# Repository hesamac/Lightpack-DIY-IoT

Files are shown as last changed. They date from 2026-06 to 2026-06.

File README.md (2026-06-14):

# Lightpack DIY — ESP32-C6 · Matter/HomeKit · Ambilight

> Replace the dead original Lightpack microcontroller (AT90USB162) with an
> **ESP32-C6**, driving the existing **DM631** LED drivers, and expose the device
> to **Apple Home (Matter)** *and* **screen-sync Ambilight** — on one chip, no
> extra hardware, no PC required for normal use.

**Status: working end-to-end.** ✅ 10 RGB zones controllable from Apple Home/Siri,
**and** live screen Ambilight via HyperHDR.

---

## What it does

The [Lightpack](https://github.com/Atarity/Lightpack) is an open-source ambient
backlight, originally a USB device driven by the (now-dead-on-macOS) Prismatik
app. This project rips out the USB MCU and turns the board into:

- A **Matter / Apple Home** smart light — **10 independent RGB zones**, each its
  own tile with tap-to-toggle, color, and brightness; controllable by Siri.
- A **wireless Ambilight** — a desktop tool (**HyperHDR**) streams screen-edge
  colors over Wi-Fi and the LEDs follow the screen in real time.

Both run in the same firmware and switch automatically: Ambilight takes over
while it's streaming, and the device returns to its Apple Home state ~2 s after
streaming stops.

---

## Hardware

| Part | Notes |
|---|---|
| Lightpack board (rev 6.x) | Original PCB with two SiTI **DM631** LED drivers (10 zones) |
| ESP32-C6-DevKitM-1 | RISC-V, Wi-Fi 6 + BLE, 4 MB flash, 3.3 V I/O |
| 12 V supply | Powers the LED rail via the barrel jack |
| 5 V source (USB charger or MP1584 buck) | Powers the board **logic** + the ESP32 |

> 🧩 **Stealth retrofit:** all the added electronics (ESP32-C6 + buck converter)
> fit **inside the original Lightpack enclosure**, so the finished unit keeps the
> original product's look — it looks just like a stock Lightpack from the outside.

### Wiring — ESP32-C6 → Lightpack (3 signals + ground)

| Signal | ESP32-C6 | Lightpack tap point |
|---|---|---|
| CLK | GPIO6  | IC1 pin 15 / DM631 DCK |
| DATA | GPIO7  | IC1 pin 16 / DM631 DAI |
| LATCH  | GPIO14 | IC1 pin 14 / DM631 /LAT |
| GND | GND | common ground (mandatory) |

> Only these three signals + GND go to the board. **Do not** connect the ESP32's
> 3.3 V/5 V pins to the Lightpack.

### Power — the key gotcha

The DM631 **logic** (VDD, ~5 V) is fed only from the board's **USB connector**,
*not* from the barrel jack (the jack/diode D2 feeds the LED rail only). So:

```
12 V barrel jack ──► LED anode rail (isolated by D2)
5 V (charger / MP1584) ──► board USB port ──► DM631 logic VDD (REQUIRED)
                       └──► ESP32-C6 power
GND ───────────────────── shared by all three
```

If the board's USB 5 V is missing, the DM631s have no logic power and the LEDs
output garbage. (3.3 V from the ESP works in practice despite the DM631's 5 V
logic-high spec; if you ever see flicker, a 74AHCT125 buffer or a 4.5 V logic
rail fixes the margin.)

### Retiring the AT90USB162 (IC1)

IC1 is disabled by **grounding its RESET pin** (all its I/O go high-impedance, so
it can't fight the ESP on the shared bus). Optionally cut IC1 pins 14/15/16 to
remove it from the bus entirely.

---

## DM631 driver

- 3-wire bit-bang (CLK/DATA/LATCH), no chip-select, MSB-first.
- 12 bits per channel (0–4095). Two DM631s daisy-chained, 32×12 bits per frame.
- **Channel order per zone: B → G → R** (matches the original woodenshark firmware).
- A small **`led_to_zone[]`** table maps logical zones to the socket numbers
  printed on the enclosure (the near chip is wired in a scrambled order).

> If only ~5 zones respond, the CLK/LATCH link between the two DM631s may need a
> jumper.

---

## Matter / Apple Home

- **Topology:** a Matter **bridge** — one Aggregator + **10 bridged Extended
  Color Lights** ("LED 1"…"LED 10"), so each zone is a first-class HomeKit
  accessory (own tile, tap-to-toggle, room, scenes).
- **Color:** HueSaturation-native (Apple drives color via `MoveToHueAndSaturation`).
  Advertises **HS + XY only** (`0x09`) — **Color Temperature is deliberately
  dropped** to dodge a HomeKit bug that paints the swatch a default light-blue
  for lights exposing CT+HS together.
- **Commissioning:** BLE. **Pairing code: `20202021`.**
- Gamma 2.2, per-zone NVS persistence, device identity (manufacturer/model/serial).

---

## Ambilight (screen sync)

- A Wi-Fi UDP receiver listens on **two** protocols:
  - **DDP** (port **4048**) — recommended; what **HyperHDR**'s "DDP" device uses.
  - **WLED** realtime (port **21324**, DRGB/DNRGB) — for WLED-native tools + testing.
- Auto Home↔Ambilight switching with a 2 s idle revert that restores the Apple
  Home colors.

### HyperHDR setup (macOS)

1. Install **HyperHDR** (`…-macOS-arm64.dmg` for Apple Silicon) from its
   [GitHub releases](https://github.com/awawa-dev/HyperHDR/releases). First launch:
   right-click → Open; grant **Screen Recording** permission.
2. **LED Layout** → *Classic*, edge counts summing to **10**.
3. **LED Controller** → type **DDP**, host = ESP32 IP, port **4048**, order **RGB**.
4. Enable the macOS screen grabber. If dim, raise HyperHDR brightness/gamma.

Quick firmware-only test (no HyperHDR) — WLED broadcast "all red":
```bash
python3 -c "
import socket, time
s = socket.socket(socket.AF_INET, socket.SOCK_DGRAM)
s.setsockopt(socket.SOL_SOCKET, socket.SO_BROADCAST, 1)
pkt = bytes([2,2]) + bytes([255,0,0])*10
for _ in range(50):
    s.sendto(pkt, ('255.255.255.255', 21324)); time.sleep(0.1)
"
```

---

## Build & flash

```bash
# Each new terminal:
source ~/esp/esp-idf/export.sh
source ~/esp/esp-matter/export.sh    # needed for builds (sets ESP_MATTER_PATH)

cd firmware
idf.py set-target esp32c6            # first time only
idf.py -p /dev/cu.usbserial-XXX build flash monitor
```

- Run `idf.py` from `firmware/` (the repo-root `CMakeLists.txt` is a junk
  placeholder). The serial port name varies with the USB socket — check
  `ls /dev/cu.*`. If "port busy": `lsof -t /dev/cu.usbserial-XXX | xargs kill`.

### Firmware layout (`firmware/main/`)

```
dm631.{c,h}              DM631 bit-bang driver + zone→socket remap
app_priv.h               shared types / defaults
app_driver.cpp           Matter color math → output layer
app_main.cpp             Matter node, bridge endpoints, Wi-Fi, startup
output_controller.{cpp,h}  single LED output layer: Home/Ambilight mode + mutex
ambilight_udp.{cpp,h}    Wi-Fi UDP receiver (WLED 21324 + DDP 4048)
```

### Languages & toolchain

- **C++** — all Matter/application code (`app_main`, `app_driver`,
  `output_controller`, `ambilight_udp`); the esp-matter / CHIP (connectedhomeip)
  SDK is C++, so the app is too.
- **C** — the `dm631` LED driver (GPIO bit-bang), called from C++ via `extern "C"`.
- Built with **ESP-IDF** + **esp-matter**, **RISC-V GCC** toolchain, target
  **ESP32-C6**. (The Ambilight test snippet is Python and runs on the Mac, not
  the device.)

---

## Status

| Item | Status |
|---|---|
| Hardware bring-up (10 zones, correct colors) | ✅ |
| Apple Home: 10 zones, color/brightness, per-tile toggle | ✅ |
| Color slider correct (light-blue bug fixed) | ✅ |
| Multi-light / Siri responsiveness | ✅ |
| Device identity (manufacturer/model/serial) | ✅ |
| Ambilight (WLED + DDP), HyperHDR verified | ✅ |
| Chip-temperature sensor | ❌ removed — Apple Home won't render bridged Matter sensors |

See [`docs/`](docs/) for the detailed dev logs.

---

## Safety

This is a do-it-yourself project that modifies the electronics of a powered
device. **Build and use it at your own risk.**

- **Power rails:** the LED rail runs at **12 V** (barrel jack); the board logic +
  ESP32 run at **5 V** (board USB). Don't cross-wire the rails, and never feed
  12 V into the ESP32 or its GPIOs.
- **Common ground:** all supplies (12 V, 5 V, ESP32) must share a ground.
- **LED current** flows through the DM631 drivers and the 12 V rail — *not*
  through the ESP32. Size the 12 V supply for your LEDs.
- **Heat:** the electronics sit inside the original enclosure; ensure adequate
  cooling. There is **no firmware thermal protection** (that feature was removed).
- This is a hobby project, **not a certified or commercial product**.

---

## Disclaimer

This is an independent, non-commercial DIY project. It is **not affiliated with,
endorsed by, or certified by** the original Lightpack project / woodenshark,
Apple, the Connectivity Standards Alliance (Matter), Espressif, WLED, or HyperHDR.
All trademarks belong to their respective owners.

The firmware uses Matter **test** vendor/product IDs and is **not** a certified
Matter or "Works with Apple Home" product — references to "Apple Home" and
"Matter" describe local compatibility only. The software is provided "as is",
without warranty of any kind (see [`LICENSE`](LICENSE)).

---

## Credits & upstream

This project builds on the original **Lightpack** by woodenshark / Atarity — the
ambient-light hardware, the original AVR firmware, and its documentation. Those
upstream sources are **GPL/CC licensed and are not bundled in this repository**;
get them from the original project:

- Original Lightpack: <https://github.com/Atarity/Lightpack>
- Original firmware: <https://github.com/woodenshark/Lightpack>

This repo contains **only the new ESP32-C6 firmware**. The DM631 driver is a
clean re-implementation; the original `LedDriver.c` is credited in the source
comments.

---

## License

This project's own code (the ESP32-C6 firmware in `firmware/`) is released under
the **MIT License** — see [`LICENSE`](LICENSE). Third-party components (ESP-IDF,
esp-matter, etc.) retain their own licenses, and the original Lightpack sources
are not included here (see **Credits & upstream** above).

---

## References

- [Lightpack original firmware](https://github.com/woodenshark/Lightpack)
- [esp-matter SDK](https://github.com/espressif/esp-matter)
- [HyperHDR](https://github.com/awawa-dev/HyperHDR)
- [ESP32-C6-DevKitM-1](https://docs.espressif.com/projects/esp-dev-kits/en/latest/esp32c6/esp32-c6-devkitm-1/)
- [SiTI DM631 datasheet](https://www.siti.com.tw/product/spec/LED/DM631.pdf)

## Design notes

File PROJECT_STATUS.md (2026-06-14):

# Lightpack DIY — ESP32-C6 · Matter/HomeKit · Ambilight — Project Status

**Last updated:** 2026-06-14  
**Status:** ✅ **Complete and working** — Apple Home (10 zones) + screen Ambilight.
**Goal:** Replace the dead Lightpack MCU (AT90USB162) with an ESP32-C6 driving the
existing DM631 LED drivers, exposed to Apple Home via Matter, plus a Wi-Fi UDP
Ambilight receiver for screen sync.

> ⚠️ The **section below this divider reflects the current, verified state.** The
> numbered sections further down are historical reference from the 2026-05-25
> bring-up; a few claims there were later superseded (corrected here and inline).
> Full history: `docs/DEVLOG-*.md`.

## Current status (2026-06-14)

### Working
- **10 RGB zones** via two daisy-chained DM631 drivers; channel order
  **B → G → R** (confirmed); logical zones remapped to the printed socket numbers
  via `led_to_zone[]`.
- **Apple Home bridge:** Aggregator + 10 bridged Extended Color Lights
  ("LED 1"…"LED 10") — each a tile with tap-to-toggle, color, brightness; Siri works.
- **Color:** HueSaturation-native; advertises **HS + XY only (`0x09`)** — Color
  Temperature deliberately dropped to fix the HomeKit "light-blue swatch" bug.
  Gamma 2.2, per-zone NVS persistence, device identity set. Pairing code **20202021**.
- **Ambilight:** Wi-Fi UDP receiver — **DDP** (port **4048**, for HyperHDR) +
  **WLED** realtime (port **21324**, DRGB/DNRGB). Auto Home↔Ambilight switching,
  2 s idle revert that restores the Apple Home state. Verified with HyperHDR (macOS).
- **Enclosure:** all added electronics (ESP32-C6 + buck converter) fit inside the
  **original Lightpack housing** — the finished build keeps the original product's
  appearance (stealth retrofit).

### Hardware — corrections vs. the historical sections below
- **Wiring:** GPIO6 = CLK, GPIO7 = DATA, GPIO14 = LATCH, GND. Three signals + ground.
- **Power:** 12 V on the barrel jack → LED rail (isolated by D2). The DM631
  **logic VDD (~5 V) comes from the board's USB connector and is REQUIRED** — not
  from the jack. *(The old "leave USB unplugged to isolate the AVR" note is wrong:
  the logic needs that USB 5 V; without it the LEDs output garbage.)* ESP32 also
  powered from 5 V. ~3.3 V signalling works in practice.
- **AT90USB162 (IC1)** isolated by **grounding its RESET pin** (I/O → Hi-Z).

### Languages & toolchain
- **C++** — all Matter/application code (`app_main.cpp`, `app_driver.cpp`,
  `output_controller.cpp`, `ambilight_udp.cpp`); required by the esp-matter /
  CHIP (connectedhomeip) C++ SDK.
- **C** — the `dm631` LED driver (GPIO bit-bang), called from C++ via `extern "C"`.
- Built with **ESP-IDF** + **esp-matter** using the **RISC-V GCC** toolchain,
  target **ESP32-C6**. (The Ambilight test snippet is Python, run on the Mac.)

### Removed
- **Chip-temperature sensor.** Firmware was proven correct (value read, scaled,
  reported), but Apple Home does **not** render *bridged* Matter sensor values
  (known Apple-side limitation — open esp-matter issues). Reverted.

### Resolved since 2026-05-25 (listed as "open" in the historical sections below)
All 10 zones working · color wheel/slider correct · multi-zone + Siri
responsiveness · fabric/commissioning · per-tile tap-to-toggle.

---

## 1. Hardware

### ESP32-C6-DevKitM-1

| Property | Value |
|---|---|
| Module | ESP32-C6-MINI-1 |
| Chip | ESP32-C6FH4 |
| Flash | 4 MB (in-package) |
| I/O voltage | 3.3 V |
| USB ports | USB-C (native USB 2.0 FS) + USB-C to UART bridge |
| Boot button | GPIO9 (strapping pin, active LOW) |
| On-board RGB LED | GPIO8 (do not use for SPI) |

### Lightpack board (standard revision 6.x)

| Component | Part | Notes |
|---|---|---|
| LED driver IC2 | SiTI DM631 | Controls zones 5–9 |
| LED driver IC3 | SiTI DM631 | Controls zones 0–4 |
| Current-limit resistors | R5, R6 = 3.9 kΩ | Use 3 kΩ only if swapped to DM633 |
| LED ports | 10 total | Each port = 1 RGB colour zone (3-LED strip) |
| Original MCU | Atmel AT90USB162 | Replaced by ESP32-C6 |
| Original interface | USB HID | Replaced by WiFi + Matter |

---

## 2. Pin Assignments

### ESP32-C6 → Lightpack DM631 wiring

| Signal | ESP32-C6 GPIO | Lightpack pad | Notes |
|---|---|---|---|
| CLK (DCK) | **GPIO6** | AT90USB162 SCK pin | SPI2 / FSPICLK |
| DATA (DAI) | **GPIO7** | AT90USB162 MOSI pin | SPI2 / FSPID |
| LATCH (LAT) | **GPIO14** | AT90USB162 LATCH pin | Software GPIO — NOT SPI CS |
| GND | GND | GND | Common ground required |
| 3.3 V | 3V3 | VCC (logic) | ESP32-C6 supplies 3.3 V logic only |

> **Power note:** The Lightpack's LEDs run at 5 V from an external supply.
> The DM631 logic interface runs at 3.3 V and is directly compatible with
> the ESP32-C6. Do NOT connect the 5 V LED rail to the ESP32-C6.

### ESP32-C6 J1 header reference (relevant pins)

| J1 Pin | GPIO | Function used |
|---|---|---|
| 11 | GPIO6 | CLK → DM631 DCK |
| 12 | GPIO7 | MOSI → DM631 DAI |
| 13 | GPIO14 | LATCH → DM631 LAT |
| 1 | 3V3 | Logic power (optional if Lightpack board has own 3.3 V reg) |
| GND | GND | Common ground |

---

## 3. DM631 Protocol — Verified Details

Source: woodenshark/Lightpack firmware (`Firmware/LedDriver.c`), confirmed against
SiTI DM631/DM633 datasheet and Ontaelio/DMdriver Arduino library.

### Electrical

- **Interface:** 3-wire (CLK, DATA, LATCH) — no chip-select
- **Logic levels:** 3.3 V compatible
- **Clock:** 1 MHz used in firmware (DM631 supports higher; 1 MHz is conservative for ribbon cable)

### SPI parameters

| Parameter | Value |
|---|---|
| SPI mode | Mode 0 (CPOL=0, CPHA=0) |
| Bit order | **MSB first** |
| Bits per channel | **12 bits** (0 = off, 4095 = full brightness) |
| Channel order per LED | **B → G → R** (blue clocked in first) |
| Channels per IC | 16 (15 used for 5 RGB LEDs + 1 padding) |
| ICs in chain | 2 (daisy-chained: ESP32 → IC1 → IC2) |

### Frame structure (48 bytes = 384 bits)

```
Byte offset   Content
──────────────────────────────────────────────────────────────────
 0– 2         0x000 (12-bit padding for IC2)
 3– 5         zone 5 Blue (12 bit), zone 5 Green (12 bit)  [packed]
 6– 8         zone 5 Red (12 bit),  zone 6 Blue (12 bit)   [packed]
 ...          zones 6, 7, 8, 9 follow in the same B-G-R order
 24–26        0x000 (12-bit padding for IC1)
 27–29        zone 0 Blue, zone 0 Green
 ...          zones 1, 2, 3, 4 follow
 45–47        zone 4 Green, zone 4 Red
```

Every two 12-bit values are packed into three bytes (MSB-first):
```
byte[0] = v0[11:4]
byte[1] = v0[3:0] | v1[11:8]
byte[2] = v1[7:0]
```

### LATCH pulse

- Fires **once**, **after** all 384 bits are clocked in for both ICs
- GPIO14: LOW → **HIGH** → LOW (active-high single pulse)
- Transfers shift-register contents to output latches on both ICs simultaneously
- No minimum pulse-width delay required at 3.3 V / ESP32 GPIO speeds (~20 ns)

### DM631 vs DM633 difference

DM631 and DM633 have **identical** shift-in protocol. DM633 adds a 7-bit global
brightness register not present on DM631. The firmware works for both chips.

---

## 4. Software / Toolchain

### Development environment

| Tool | Version | Location |
|---|---|---|
| ESP-IDF | v5.3.0 | `~/esp/esp-idf` |
| RISC-V GCC | 13.2.0 | `~/.espressif/tools/riscv32-esp-elf/` |
| OpenOCD | v0.12.0-esp32 | `~/.espressif/tools/openocd-esp32/` |
| esp-matter | latest main | `~/esp/esp-matter` |
| Python (venv) | 3.14.4 | `~/.espressif/python_env/idf5.3_py3.14_env/` |

**To activate in a new terminal:**
```bash
source ~/esp/esp-idf/export.sh
source ~/esp/esp-matter/export.sh
```

### Firmware project

**Location:** `~/Documents/Project/Lightpack\ DIY/firmware/`

```
firmware/
├── CMakeLists.txt                # top-level build, links to esp-matter
├── partitions.csv                # 4 MB flash layout with OTA + factory NVS
├── sdkconfig.defaults            # BT, WiFi, Matter cluster pruning
├── sdkconfig.defaults.esp32c6    # target lock
└── main/
    ├── CMakeLists.txt
    ├── dm631.h / dm631.c         # DM631 SPI driver
    ├── app_priv.h                # shared types and defaults
    ├── app_driver.cpp            # Matter ↔ DM631 bridge (colour math, per-zone state)
    └── app_main.cpp              # Matter node, 10 endpoints, event loop
```

### Build status

| Item | Status |
|---|---|
| `idf.py set-target esp32c6` | ✓ |
| `idf.py build` | ✓ — zero errors, 1.71 MB (13% headroom) |
| Binary | `build/lightpack.bin` |
| Matter device type | Extended Color Light × 10 (one per zone) |
| Colour modes supported | On/Off, Brightness, Hue/Saturation, Color Temperature, CIE XY |
| Per-zone independent control | ✓ 10 separate Matter endpoints → 10 HomeKit tiles |
| RGB colour wheel in Apple Home | ✓ confirmed (FeatureMap + ColorCapabilities fix) |
| NVS persistence | ✓ (deferred write per-endpoint, per-zone) |
| OTA update support | ✓ (partition table includes OTA slots) |

### Known TODOs in firmware

- **Button (GPIO9):** `app_driver_button_init()` returns NULL — button
  toggle and 5-second factory-reset long-press not yet wired in.
  Workaround: `idf.py erase-flash flash` for factory reset.
- **Prismatik API (future):** TCP:3636 Prismatik API for
  computer-screen-reactive ambilight. HomeKit per-zone control is now
  fully implemented; Prismatik is a future enhancement.
- **BLE re-advertising after fabric removal:** `kBLEDeinitialized` may
  fire before `kFabricRemoved`, preventing BLE re-advertising. Needs
  investigation (not reproduced since switching to `kAllSupported`).
- **Hardware wiring:** Not yet connected to Lightpack board (see § 5).

---

## 5. Wiring Status

| Connection | Status |
|---|---|
| ESP32-C6 GPIO7 → Lightpack DATA pad (right edge / J1) | ⬜ Not yet wired |
| ESP32-C6 GPIO6 → Lightpack CLK pad (right edge / J1) | ⬜ Not yet wired |
| ESP32-C6 GPIO14 → Lightpack LATCH pad (right edge / J1) | ⬜ Not yet wired |
| ESP32-C6 GND → Lightpack GND pad (right edge / J1) | ⬜ Not yet wired |
| 5 V external supply → Lightpack LED rail | ⬜ Not yet connected |
| AT90USB162 removed / bypassed | ⬜ Pending |

### Preferred solder points — NEXT_BOARD connector (J1), right edge of PCB

The Lightpack board has five dedicated labeled pads on its right edge (the J1
"NEXT_BOARD" daisy-chain connector). These are the easiest and most reliable
connection points — no need to solder directly to IC2's SOP24 pins.

```
Lightpack right edge          ESP32-C6 DevKitM-1
────────────────────          ──────────────────
DATA  pad  ──────────────────► J1 Pin 12 (GPIO7)
CLK   pad  ──────────────────► J1 Pin 11 (GPIO6)
LATCH pad  ──────────────────► J1 Pin 13 (GPIO14)
GND   pad  ──────────────────► GND
VCC   pad  — leave unconnected (ESP32-C6 has its own 3.3 V supply)
```

> **Note:** The DATA pad on J1 connects to the same `DATA1` net as IC2 Pin 2.
> Soldering to either point is electrically identical; J1 is far easier.

---

## 6. Next Steps — Hardware Build

### Step 1 — Bypass or remove the AT90USB162

The original MCU drives the same CLK/DATA/LAT lines. It must be
electrically isolated before the ESP32-C6 is connected, or it will
fight for the bus.

Options (choose one):
- **Remove the IC** (recommended if you have hot-air rework tools)
- **Lift pins** DCK, DAI, LAT on the AT90USB162 so it cannot drive the lines
- **Leave it in reset** by holding the RESET pin LOW (check schematic for reset pull-up)

### Step 2 — Locate the DM631 signal pads on the Lightpack board

Using the Lightpack 6.0L schematic (Eagle CAD files in the Lightpack GitHub repo):
- Find the pads where the AT90USB162 drives IC2/IC3 (the two DM631 chips)
- CLK and DATA are shared between both ICs (daisy-chained)
- LAT is a single line that latches both ICs simultaneously

### Step 3 — Wire ESP32-C6 to Lightpack board

Use short, direct wires (< 15 cm preferred for signal integrity at 1 MHz).

Solder to the **J1 "NEXT_BOARD" pads on the right edge** of the Lightpack PCB
(five labeled pads: VCC, GND, DATA, CLK, LATCH):

```
ESP32-C6 DevKitM-1          Lightpack board (J1 right-edge pads)
──────────────────          ──────────────────────────────────────
J1 Pin 12 (GPIO7)  ──────►  DATA  pad
J1 Pin 11 (GPIO6)  ──────►  CLK   pad
J1 Pin 13 (GPIO14) ──────►  LATCH pad
GND                ──────►  GND   pad
                             VCC   pad — leave unconnected
```

No level shifter needed — both sides are 3.3 V logic.

> **Alternative:** DATA can also be soldered directly to IC2 Pin 2 (DAI) on
> the DM631 chip — same net, but the J1 edge pad is far easier to work with.

### Step 4 — Power

- The ESP32-C6-DevKitM-1 is powered independently via its own USB-C cable
- The Lightpack board's 5 V LED supply connects to its existing power jack
- The shared GND is the only electrical connection required for the power domains

### Step 5 — Flash and commission

```bash
# In a terminal with environment sourced:
cd ~/Documents/Project/Lightpack\ DIY/firmware

# Flash (NVS preserved — use if already commissioned)
idf.py -p /dev/cu.usbserial-210 flash

# Flash + erase (wipes commissioning data — use for first-time or re-commissioning)
idf.py -p /dev/cu.usbserial-210 erase-flash flash
```

First boot output will show a Matter QR code. Open the iPhone **Home** app
→ Add Accessory → scan the QR code. All 10 zones appear as separate tiles.

### Step 6 — Verify DM631 output

At boot, the firmware runs a 3-colour diagnostic sequence (RED → GREEN → BLUE,
1.5 s each) across all zones. Confirm all 10 LED strips cycle through the colours
in the correct order. If a strip shows the wrong colour, cross-reference the
zone index with the DM631 channel mapping in § 3.

### Step 7 — Name zones in the Home app

After confirming hardware, rename zones in the Home app (tap tile → ✎) to
match physical strip positions. Reference mapping:

| HomeKit tile | Endpoint | DM631 IC | Physical position (to be confirmed) |
|---|---|---|---|
| Lightpack (Zone 0–4) | 1–5 | IC3 (near, zones 0–4) | TBD after hardware test |
| Lightpack (Zone 5–9) | 6–10 | IC2 (far, zones 5–9) | TBD after hardware test |

### Step 8 — Add button support (optional)

Edit `main/app_driver.cpp` — the `app_driver_button_init()` stub is
already in place. Wire the ESP32-C6 BOOT button (GPIO9, active LOW) to
toggle on/off and trigger factory reset on 5-second press.

### Step 9 — Prismatik API (future)

Add a TCP server on port 3636 implementing the Prismatik API v1.3
(`lock`, `setcolor:N-R,G,B;`, `setbrightness`, `setstatus`) so the
existing Prismatik ambilight software can drive per-zone colours over WiFi.

---

## 7. References

| Document | Location |
|---|---|
| Lightpack DIY build guide | `Lightpack-docs-master/Lightpack_DIY.md` |
| Lightpack basics | `Lightpack-docs-master/Lightpack_basics.md` |
| Prismatik API v1.3 | `Lightpack-docs-master/Prismatik_API.md` |
| ESP32-C6-DevKitM-1 datasheet | `datenblatt-2992163-espressif-esp32-c6-devkitm-1-n4-entwicklungsboard.pdf` |
| Lightpack firmware source | https://github.com/woodenshark/Lightpack |
| DM631 Arduino library | https://github.com/Ontaelio/DMdriver |
| ESP-IDF docs | https://docs.espressif.com/projects/esp-idf/en/v5.3/ |
| esp-matter docs | https://docs.espressif.com/projects/esp-matter/en/latest/ |

---

## 8. Session Log — 2026-05-10

### What was done

The device had already been wired, flashed, and commissioned in earlier sessions
(see `lightpack-diy-session-log.md`). This session focused on two software bugs
that prevented correct behaviour in Apple Home.

---

### Bug 1 — Apple Home shows warm/cool slider instead of RGB colour wheel

**Symptom:** After commissioning, the accessory tile in Apple Home only offers a
colour-temperature (warm/cool) slider. No RGB colour wheel is reachable.

**Root cause — ODR violation in the esp-matter SDK:**
Both `esp_matter_cluster.cpp` (legacy) and the generated
`extended_color_light_device.cpp` export the symbol
`esp_matter::cluster::color_control::create()`. The two translation units define
different `config_t` structs with `color_capabilities` at different byte offsets.
When the legacy version wins the linker race it reads from the wrong offset and
writes `0` to the `ColorCapabilities` attribute. Apple Home interprets
`ColorCapabilities = 0` as "no colour modes supported" and hides the colour wheel.

**Fix applied (`main/app_main.cpp`):**
After the endpoint is created, write `ColorCapabilities = 0x0009`
(bit 0 = HueSaturation, bit 3 = XY) directly onto the live attribute object —
this bypasses the struct-offset mismatch entirely.

**Status: ❌ Partially fixed.** ColorCapabilities was set correctly but Apple Home
still showed the temperature slider. Full fix completed in Session 2026-05-25.

---

### Bug 2 — Device undiscoverable after removing accessory from Apple Home

**Symptom:** After removing the accessory in Apple Home, the device never reappears
under "Nearby Accessories" and cannot be re-added.

**Root cause:**
The `kFabricRemoved` event handler called
`OpenBasicCommissioningWindow(..., kDnssdOnly)`. The device has no active WiFi at
that point, so DNS-SD discovery fails and BLE advertising is suppressed.

**Fix applied (`main/app_main.cpp`, `kFabricRemoved` case):**

```cpp
(void)mgr.OpenBasicCommissioningWindow(
    chip::System::Clock::Seconds16(k_timeout_seconds),
    chip::CommissioningWindowAdvertisement::kAllSupported);  // was kDnssdOnly
```

**Status: ⚠️ Not yet fully confirmed.** Not reproduced since fix applied.

---

### Other findings (2026-05-10)

| Finding | Detail |
|---|---|
| `matter factoryreset` shell command fails | Returns `Error: 47`. Use `idf.py erase-flash flash` instead. |
| UART port at the time | `/dev/cu.usbserial-110`, 115200 baud |

---

## 9. Session Log — 2026-05-25

### Goals

1. Add independent per-zone colour and brightness control for all 10 LED strips
   via Apple HomeKit (each zone = its own light tile with colour wheel).
2. Fix RGB colour wheel not appearing in Apple Home.

---

### Change 1 — Per-zone independent control (all three firmware files)

**Problem:** The original firmware created one Matter endpoint and called
`dm631_set_all()`, sending the same colour to all 10 zones.

**Solution:** Refactored to 10 Matter endpoints — one per LED zone.

#### `app_priv.h`
- Added `NUM_LIGHT_ZONES 10` constant.
- Added `app_driver_register_endpoint(zone, endpoint_id)` declaration —
  wires the zone→endpoint mapping used by the attribute callback.

#### `app_driver.cpp`
- Replaced 8 global colour-state variables with `zone_state_t s_zone_state[10]`
  — each zone has independent power, brightness, hue, saturation, XY, colour temp.
- `apply_to_leds()` → `apply_zone_to_leds(zone)`, now calls
  `dm631_set_zone(zone, color)` then `dm631_update()`.
- `endpoint_to_zone(endpoint_id)` maps incoming Matter endpoint IDs to zone
  indices in O(10).
- `app_driver_attribute_update()` looks up the zone before acting; events for
  unrelated endpoints are silently ignored.
- `app_driver_light_set_defaults(endpoint_id)` restores per-zone NVS state at boot.

#### `app_main.cpp`
- `light_endpoint_id` (singular) → `light_endpoint_ids[10]` (array).
- Loop 0–9: create endpoint, register zone, apply colour feature fix, set
  deferred persistence on attributes that exist.
- After `esp_matter::start()`: loop 0–9 to restore NVS state for each zone.

**Result in Apple Home:** 10 separate light tiles, each with independent
colour wheel, brightness slider, and on/off toggle.

---

### Change 2 — `CONFIG_ESP_MATTER_MAX_DYNAMIC_ENDPOINT_COUNT` raised to 11

**Problem:** Boot crash after zone 0:
```
E data_model: Dynamic endpoint count cannot be greater than
              CONFIG_ESP_MATTER_MAX_DYNAMIC_ENDPOINT_COUNT:2
```
`sdkconfig.defaults` had the count set to 2 (an old project override — the
Kconfig default is 16).

**Root cause of the off-by-one:** The esp-matter data model check is
`get_count(node) < MAX`. The root node endpoint (endpoint 0) is included in
`get_count()`, so `MAX=10` only allows 9 user endpoints.

**Final fix:** `CONFIG_ESP_MATTER_MAX_DYNAMIC_ENDPOINT_COUNT=11` in both
`firmware/sdkconfig.defaults` and `firmware/sdkconfig`.

**Rule:** Always set `MAX_DYNAMIC_ENDPOINT_COUNT = (number of user endpoints) + 1`.

**Verified:** All 10 zones (endpoints 1–10) created successfully:
```
I app_main: Zone 9 → endpoint id 10
I chip[ZCL]: Endpoint a On/off already set to new value
```

---

### Change 3 — RGB colour wheel fix (FeatureMap + ColorCapabilities)

**Problem:** Apple Home showed only a warm/cool colour-temperature slider,
no RGB colour wheel, even with `ColorCapabilities = 0x0009`.

**Root cause (fully diagnosed):**
Apple Home reads **both** `ColorCapabilities` *and* the `FeatureMap` attribute
on the ColorControl cluster. Without the HueSaturation bit in `FeatureMap`,
Apple Home ignores `ColorCapabilities` and shows only a colour-temperature slider.

The `FeatureMap` was not being updated because `hue_saturation::add()` calls
`update_feature_map()` internally, but this fails silently due to an ODR
violation in the esp-matter SDK:

- Both `esp_matter_feature.cpp` (legacy) and the generated `color_control.cpp`
  export `esp_matter::cluster::color_control::feature::hue_saturation::add()`.
- When the linker picks the legacy version, its `update_feature_map()` uses the
  legacy attribute lookup, which cannot find the `FeatureMap` attribute created
  by the generated `extended_color_light::create()` path.
- Result: log message `"Feature map attribute cannot be null"`, FeatureMap NOT
  updated, but `CurrentHue` / `CurrentSaturation` attributes ARE created.

**Fix in `configure_color_endpoint()` (`main/app_main.cpp`):**

Three-step approach after each `extended_color_light::create()` call:

1. **Call `hue_saturation::add()`** — creates `CurrentHue`, `CurrentSaturation`,
   and HS commands. The FeatureMap update fails (harmless warning) but attribute
   creation succeeds.

2. **Force `ColorCapabilities = 0x0009`** (HS bit 0 + XY bit 3) — bypasses the
   config-struct ODR mismatch that can write 0 here.

3. **Force `FeatureMap |= 0x0009`** on the ColorControl cluster (attribute
   `0xFFFC` = `Globals::Attributes::FeatureMap::Id`) — the missing piece:
   ```cpp
   attribute_t *fm_attr = attribute::get(endpoint_id, ColorControl::Id, 0xFFFC);
   esp_matter_attr_val_t fm_val = esp_matter_invalid(NULL);
   attribute::get_val(fm_attr, &fm_val);
   uint32_t new_fm = fm_val.val.u32 | 0x0009u;   // OR in HS(bit0) + XY(bit3)
   attribute::set_val(fm_attr, &esp_matter_bitmap32(new_fm));
   ```

**Verified in boot log (all 10 endpoints):**
```
I app_main: ep 1 ColorCapabilities    = 0x0009
I app_main: ep 1 ColorControl FeatureMap = 0x00000019
```
`0x0019` = HS (bit 0) + XY (bit 3) + CT (bit 4, already set by `create()`).

**End-to-end result:** After re-commissioning (erase-flash clears iOS cache),
Apple Home shows an RGB colour wheel on all 10 zone tiles. ✅

---

### Change 4 — Deferred persistence NULL guard

`set_deferred_persistence()` was being called for `CurrentX` and `CurrentY`
even when those attributes don't exist in HS-only mode, logging
`"Attribute cannot be NULL"` twice per zone at boot.

**Fix:** Wrapped all `set_deferred_persistence` calls in a guard lambda:
```cpp
auto defer_if_exists = [&](uint32_t cluster_id, uint32_t attr_id) {
    attribute_t *a = attribute::get(ep_id, cluster_id, attr_id);
    if (a) attribute::set_deferred_persistence(a);
};
```

---

### Other findings (2026-05-25)

| Finding | Detail |
|---|---|
| `sdkconfig.defaults` in project root | File contained literal `"404: Not Found"` — corrupted. Real file is `firmware/sdkconfig.defaults`. |
| UART port | `/dev/cu.usbserial-210`, 115200 baud (changed from `-110`) |
| Hard reset method | Use `python3 -m esptool --chip esp32c6 -p /dev/cu.usbserial-210 run`. Direct DTR/RTS toggling via pyserial can accidentally trigger download mode on this board. |
| Firmware binary size | 1.71 MB (13% flash headroom) |

---

### Next steps (after hardware wiring)

1. **Hardware wiring** — connect ESP32-C6 to Lightpack board (see § 5 & 6).
   Verify all 10 LED zones light up and respond to HomeKit commands.
2. **Zone-to-position mapping** — rename zones 0–9 in the Home app to match
   physical strip positions after DM631 channel order is confirmed on hardware.
3. **BLE re-advertising after fabric removal** — test whether the device
   reappears in "Nearby Accessories" after removing from the Home app.
4. **Button support (GPIO9)** — wire BOOT button for toggle + 5 s factory-reset
   long-press (`app_driver_button_init()` stub already in place).
5. **Prismatik API (future)** — TCP server on port 3636 for computer-screen
   reactive ambilight (`lock`, `setcolor:N-R,G,B;`, `setbrightness`).

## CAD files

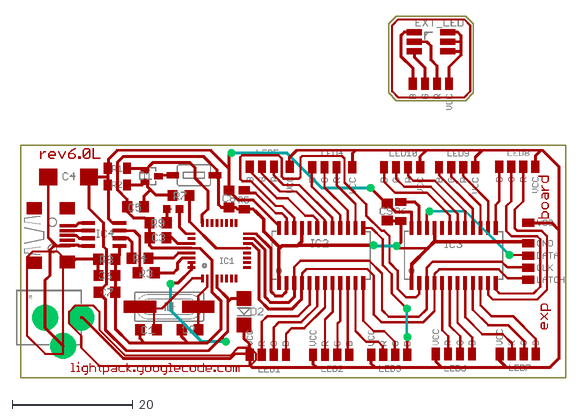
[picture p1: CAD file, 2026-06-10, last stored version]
Lightpack-master/Hardware/Lightpack-board.dxf
91.2 x 60.0

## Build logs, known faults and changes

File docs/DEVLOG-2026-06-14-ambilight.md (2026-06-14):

# Lightpack DIY — Dev Log: Ambilight + Temp-sensor attempt (2026-06-14)

Adding the **screen-sync Ambilight** feature (the original Lightpack purpose)
to the working Matter/Apple-Home controller, plus an attempt at a chip-temp
sensor (added, then removed).

**Result:** Ambilight works end-to-end — HyperHDR on macOS drives the 10 zones
from the screen in real time, while Apple Home control is fully preserved
(no re-pair, same Wi-Fi transport).

---

## Commits

| Commit | What |
|---|---|
| `fb5b6fe` | Wi-Fi UDP ambilight (WLED) + Home/Ambilight mode switching |
| `aca6ee2` | Add DDP protocol to the receiver (for HyperHDR) |

(The temperature sensor work was implemented, verified-correct in firmware, then
**reverted** — see below — so it is not in the tree.)

---

## Architecture decision — Option B

Goal: support two modes in one firmware — **Home** (Apple Home via Matter) and
**Ambilight** (live screen colours) — and switch between them.

Options weighed:
- **A. Pure Thread** — best Home latency, but no Wi-Fi for Ambilight.
- **B. Matter-over-Wi-Fi + Wi-Fi UDP Ambilight** ← chosen.
- **C. Thread + Wi-Fi coexistence** — heaviest (two stacks share one 2.4 GHz
  radio → flash/RAM pressure + airtime contention).
- **D. Thread + USB-serial Ambilight** — great latency, but tethers the Mac.

**Chosen B** because: no migration, **no re-pair**, keeps the whole working
device (bridge, names, identity, light-blue fix) intact, lowest risk, fits the
4 MB flash, and Ambilight smoothness comes from **local UDP (~1–5 ms)** — not
from Matter — so dragging the Home colour wheel staying on Wi-Fi latency is
irrelevant (Ambilight is the dynamic-colour source).

Prismatik is dead on macOS 26; the modern sender is **HyperHDR**.

---

## Ambilight implementation

Two small modules, one clean output seam:

### `output_controller.{cpp,h}` — single LED output layer
- Two source buffers: **HOME** (per-zone, from Matter) and **AMBILIGHT**
  (full frame, from UDP). Exactly one drives the DM631 at a time.
- **Mutex-protected** — the Matter thread and the UDP task never interleave a
  384-bit frame.
- HOME colours are always kept current, so when Ambilight stops the previous
  Apple Home state is **restored**.
- Auto switching: a frame activates AMBILIGHT; **~2 s** with no frame reverts to
  HOME (`output_tick()` is called from the UDP task's receive timeout).
- `app_driver` was rerouted: `apply_zone_to_leds()` now hands its computed
  colour to `output_set_home_zone()` instead of writing the DM631 directly.

### `ambilight_udp.{cpp,h}` — UDP receiver task
- One task, `select()` on **two** sockets:
  - **21324 WLED** realtime: DRGB (proto 2) + DNRGB (proto 4).
  - **4048 DDP**: Distributed Display Protocol.
- 8-bit sRGB → 12-bit with **gamma 2.2** (matches the Home path).
- Robust parsing: length/protocol checks, malformed packets ignored, partial
  frames accumulate.

### The HyperHDR gotcha → DDP
HyperHDR's **"WLED" device requires the target to also answer a WLED HTTP
`/json` handshake** (LED-count discovery) — our UDP-only receiver can't, so the
WLED device type won't connect. **DDP needs no handshake**, so it's the clean
path for a custom device. We kept WLED too (for the broadcast test + WLED tools).

---

## Verified HyperHDR setup (macOS)

1. Install **HyperHDR** — `…-macOS-arm64.dmg` (Apple Silicon) from the GitHub
   releases. First launch: right-click → Open (un-notarized), and grant
   **Screen Recording** permission.
2. **LED Layout** tab → **Classic**, edge counts summing to **10** (e.g.
   3/3/2/2). This sets the LED count.
3. **LED Controller** → Type **DDP**, Host = ESP32 IP, Port **4048**, order
   **RGB**.
4. Enable the macOS screen grabber. Allow network access if prompted.
5. If it looks dim, raise HyperHDR brightness/gamma (our firmware already
   applies gamma 2.2).

Quick firmware-only test (no HyperHDR), WLED broadcast "all red":
```bash
python3 -c "
import socket, time
s = socket.socket(socket.AF_INET, socket.SOCK_DGRAM)
s.setsockopt(socket.SOL_SOCKET, socket.SO_BROADCAST, 1)
pkt = bytes([2,2]) + bytes([255,0,0])*10
for _ in range(50):
    s.sendto(pkt, ('255.255.255.255', 21324)); time.sleep(0.1)
"
```
Monitor shows `-> Ambilight mode`, then `-> Home mode (ambilight idle …)`.

---

## Temperature sensor — attempted and removed

Goal was chip-temperature monitoring + thermal safety, with a "Lightpack Temp"
sensor in Apple Home.

**What was proven (via chip-shell `attribute get` + monitor logs):** the
firmware was **correct** — the ESP32-C6 internal sensor was read, scaled ×100,
written to the Temperature Measurement cluster, and reported (value climbed
28→33 °C with warm-up, no errors). Apple Home still showed **0 °C**.

**Conclusion:** a **known Apple-side limitation** — Apple Home does not reliably
render **bridged** Matter sensor values (multiple open esp-matter issues; same
family as the bridged-colour quirk). Confirmed even after a clean re-pair.
Web research showed the common fixes (×100 scaling, dedicated endpoint) — both
of which we already did.

**Also noted:** the C6 internal sensor lacks precise factory calibration on this
unit — absolute reading was ~18 °C low and shifted with the chosen measurement
range; per Espressif it's reliable only for *trend*, not absolute precision.

**Decision:** the Home tile being the only broken part (the value was correct
internally), and the user not needing it, the whole feature was **reverted**
(`git checkout` + delete) back to `e42d959`.

---

## Final state

- ✅ Matter/Apple Home: 10 zones, colour/brightness, bridge, identity, light-blue
  fix — all intact, no re-pair.
- ✅ Ambilight: WLED (21324) + DDP (4048), auto Home↔Ambilight switching, 2 s
  revert with Home-state restore; HyperHDR verified.
- ⬜ Optional follow-ups: Home "Ambilight" on/off switch endpoint; make Home
  "Off" force-exit Ambilight; Step 7 cleanup (dedupe gamma, log levels).
- Binary ~1.72 MB / 1.875 MB partition (12 % free).

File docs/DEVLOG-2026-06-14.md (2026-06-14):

# Lightpack DIY — Dev Log (2026-06-13/14)

HomeKit polish session. The hardware and basic Matter control were already
working (see [DEVLOG-2026-06.md](DEVLOG-2026-06.md)); this session fixed the
remaining UX issues and chased down a genuine Apple Home bug.

**Headline result:** the long-standing "light-blue color slider" bug is
**solved**, plus the multi-light update storm is gone, zones now map to the
printed socket numbers, and each light carries custom device identity.

---

## Commits this session

| Commit | What |
|---|---|
| `cf2a43a` | LED→socket remap + rename tiles "Zone N" → "LED N" |
| `bd55f20` | HS-native simplification (multi-light update storm fix) |
| `9b4b95b` | Device identity (manufacturer / model / serial) |
| `0ff5cd2` | **Light-blue swatch fix** — advertise HS+XY only (drop Color Temperature) |

All pushed to `github.com/hesamac/Lightpack-DIY-IoT` `main`.

---

## 1. Zone → LED socket remap

The firmware zone indices didn't line up with the socket numbers printed on the
enclosure. Measured per-socket on the board: the near DM631 (sockets 1–5) is
wired in a scrambled order; the far DM631 (sockets 6–10) is sequential.

Fix: a one-line indirection table in `dm631.c` so logical zone N drives box
socket N+1. `build_frame()` and the Matter layer are untouched.

```c
// Which physical DM631 zone each LED socket is wired to (LED 1 = index 0):
//   LED 1 → Zone 4     LED 6  → Zone 5
//   LED 2 → Zone 3     LED 7  → Zone 6
//   LED 3 → Zone 0     LED 8  → Zone 7
//   LED 4 → Zone 1     LED 9  → Zone 8
//   LED 5 → Zone 2     LED 10 → Zone 9
static const uint8_t led_to_zone[DM631_NUM_ZONES] = {4, 3, 0, 1, 2, 5, 6, 7, 8, 9};
```

Tiles were also renamed "Zone N" → "LED N" (NodeLabel; shows on next pairing).

---

## 2. HS-native simplification (fixed the multi-light storm)

**Symptom (Issue 2):** turning all 10 lights on/off together, or asking Siri to
set a colour, produced 2–3 s of chaotic flicker before settling.

**Root cause:** an over-engineered colour path. A "mirror" system wrote every
colour change across all three representations (HS↔XY↔CT) on every command, and
ColorControl was handled in *two* callbacks. A single `MoveToHueAndSaturation`
fanned out into ~8 LED applies plus a flood of outbound attribute reports — and
with 10 zones at once it overwhelmed the Matter pipeline.

**Diagnosis aid:** confirmed via an on-device command trace that Apple Home
drives colour exclusively with `MoveToHueAndSaturation` (command `0x06`) — i.e.
the device is **HueSaturation-native**, so the XY-forcing/mirroring was fighting
Apple.

**Fix:** drive the LED from HS as the single source of truth; handle
ColorControl in exactly one place (`MatterPostAttributeChangeCallback`, which
fires *after* the value is stored so it always reads fresh). Deleted the mirror,
the boot HS→XY normalise, the `ScheduleWork` trampoline, the re-entry guard, the
mismatched RGB↔XY matrices, and the stale-reading PRE_UPDATE branch.
Result: one command → one apply → one DM631 frame. **−168 lines.** Storm gone.

---

## 3. Device identity

Each LED tile now reports its own identity via the Bridged Device Basic
Information cluster (shown in Apple Home → accessory details):

- Hersteller (VendorName) = `Hesam DIY & Lightpack`
- Modell (ProductName) = `Lightpack IOT`
- Seriennummer (SerialNumber) = `20202021`

Bridge-level serial set via `CONFIG_USE_TEST_SERIAL_NUMBER`. (Bridge-level
vendor/product *name* come from CHIP's compiled provider and would need a custom
`DeviceInstanceInfoProvider` to override — left as-is. Vendor/Product *IDs*
remain the Matter test IDs, so Apple still shows "uncertified".)

---

## 4. The light-blue slider — the long one

**Symptom:** set a light to a colour → the LED is correct, but on reopening the
Home app the colour swatch/slider shows a default **light blue**. Persisted
across many earlier fix attempts.

### How we finally pinned it

1. **Instrumented the device** with the chip shell
   (`matter esp attribute get <ep> 0x300 <attr>`). With a zone set to green the
   device held *perfect, consistent* green: ColorMode=0 (HS), CurrentHue=84,
   CurrentSat=254, CurrentX/Y = green, CT = 444 mireds (warm). **None** of the
   representations is light blue → Apple was showing its **generic default
   swatch**, i.e. not applying our reported colour at all on a fresh read.
2. **A/B tested the topology.** Rebuilt non-bridged (one composed accessory
   instead of the Aggregator + bridged lights). Still light blue — *and* it lost
   tap-to-toggle. So the bridge was **not** the cause (and is strictly better:
   separate tiles + tap-to-toggle at no extra cost). Bridge restored.
3. **Web search** found the real cause: a widely-reported **Apple-side bug** —
   HomeKit mis-handles lights that advertise **Color Temperature alongside
   Hue/Saturation**, painting the swatch a default white/blue on a fresh read.
   It even affects CT-exposing Philips Hue bulbs. (Hubitat / Home-Assistant /
   Hue community threads all describe the exact symptom.)

### The fix

Advertise **HS + XY only** — drop Color Temperature from `ColorCapabilities`
and `FeatureMap` (`0x19` → `0x09`, CT bit 4 cleared) in
`configure_color_endpoint()`. Apple then treats the device as a pure colour
light and reads the real hue/saturation. **Confirmed fixed.**

Trade-off: no "Temperature" tab in the Apple colour picker — irrelevant for an
RGB device. And because it's topology-independent, we kept the bridge (separate
tap-to-toggle tiles) *and* got correct colour.

---

## Final state — fully working

- 10 RGB zones, correct colour + brightness, mapped to the printed sockets
- Per-zone tap-to-toggle tiles, named by LED, with custom manufacturer/model/serial
- Fast multi-light & Siri response (storm fixed)
- Colour slider shows the real colour, even on app reopen
- Clean, simplified codebase; every step checkpointed on GitHub

## Lessons / gotchas

- **Apple Home is HueSaturation-native** for colour control — don't force XY/CT.
- **Don't advertise Color Temperature on an RGB-only light** for Apple Home, or
  the swatch renders as a default white/blue on fresh reads.
- **Instrument before guessing.** The chip-shell attribute reads (and the
  command trace) ended ~5 cycles of guess-and-flash by proving the device state
  was correct and the issue was Apple-side.
- **A/B test structural hypotheses** before big rewrites — it disproved the
  bridge theory cheaply and redirected us to the real cause.
- Serial port name varies with the USB socket; a stale `idf.py monitor` keeps
  the port locked (`lsof -t /dev/cu.usbserial-XXX | xargs kill`).

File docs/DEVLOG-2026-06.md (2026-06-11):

# Lightpack DIY — Dev Log (June 2026)

Replacing the original **AT90USB162** microcontroller on a Lightpack rev6.0L
board with an **ESP32-C6** to expose the 10 RGB LED zones as Apple HomeKit
(Matter) lights.

**Result of this week: fully working end-to-end.** All 10 zones drive correct
colour and brightness from Apple Home; all known UI bugs resolved.

---

## Hardware

### Board topology
- **IC1** = AT90USB162 (original MCU, being retired)
- **IC2** = DM631 LED driver, near chip, zones 0–4
- **IC3** = DM631 LED driver, far chip, zones 5–9 (daisy-chained after IC2)
- 3-wire serial bus shared by both DM631s: **CLK, DATA, LATCH**

### ESP32-C6 wiring
| ESP32-C6 | Signal | Board point |
|---|---|---|
| GPIO6  | CLK | IC1 pin 15 / IC2 DCK |
| GPIO7  | DATA1  | IC1 pin 16 / IC2 DAI |
| GPIO14 | LATCH  | IC1 pin 14 / IC2 /LAT |
| GND | GND | any board ground |

**Do NOT connect ESP32 3.3V/5V to the board.** Three signal wires + GND only.
All supplies must share a common ground.

### Power (the key hardware lesson)
- **12V** on the power jack feeds **only the LED anode rail** (isolated by diode
  D2/SS14). It does **not** power the DM631 logic.
- **DM631 VDD (pin 24) = +5V**, which on this board comes **only from the
  board's USB connector**. With the board powered from 12V alone, VDD read 0V
  and the chips ran on input-pin leakage → chaotic, meaningless LED output.
- **Fix:** feed 5V into the board's USB port (a phone charger, or the project's
  MP1584 buck — VBUS + GND only, leave D+/D- unconnected). Confirmed: VDD = 5.22V.
- LED rail correctly stays at 12V (the strips are 12V type).

### DM631 protocol (verified)
- Frame: `[0pad][z5..z9]` then `[0pad][z0..z4]`, 32 × 12-bit = 384 bits, MSB-first,
  LATCH pulse after.
- **Channel order per zone: B → G → R** (matches the original woodenshark
  `Lightpack-master/Firmware/LedDriver.c`; the `at90usb162-firmware` copy's
  B→R→G is wrong).
- Runs reliably at full ESP32 GPIO speed (no added bit delays) now that VDD = 5V.
- Logic-level note: DM631 VIH(min) = 3.5V vs ESP32's 3.3V is marginally out of
  spec but works in practice. If it ever glitches: drop the logic rail to ~4.5V
  or add a 74AHCT125 buffer.

### Retiring IC1
- IC1 was held off by grounding its RESET pin (pins go Hi-Z → no bus contention).
- RESET has a 20kΩ pull-up to +5V, so a broken ground tie lets IC1 wake and
  fight the bus — verify RESET reads ~0V if in doubt.
- Cleanest permanent fix: cut IC1's leads at the package body (at minimum pins
  14/15/16) — the PCB pads/traces and the ESP32→DM631 path survive; leftover
  pin stubs are inert.

---

## Firmware

ESP-IDF + esp-matter project in `firmware/`. Standalone hardware test in
`dm631_test/` (no Matter — all-white, per-zone RGB sweep, brightness ramp,
rainbow).

### Matter model
- **Bridge topology:** EP1 = Aggregator, EP2–EP11 = bridged Extended Colour
  Lights named "Zone 1".."Zone 10". Each becomes a first-class HomeKit accessory
  with tap-to-toggle, its own room, and independent scenes/automations.
- `CONFIG_ESP_MATTER_MAX_DYNAMIC_ENDPOINT_COUNT = 12` (root + aggregator + 10).
- ColorControl advertises HS + XY + CT (FeatureMap / ColorCapabilities = 0x19),
  set manually after endpoint creation due to an esp-matter ODR FeatureMap bug.

### Colour pipeline
- HSV/CT/XY → RGB, **gamma 2.2**, 12-bit per channel to the DM631.
- Colour changes are **mirrored across HS/XY/CT** so any controller readback is
  consistent (with a re-entry guard so mirror writes don't recurse).
- Zones **normalise to XY colour mode at boot** — Apple Home renders the slider
  only from XY/CT; an HS-mode zone showed a generic light-blue fill.

---

## Bugs fixed this week

| Symptom | Root cause | Fix |
|---|---|-----|
| Chaotic LEDs / no white | DM631 logic unpowered (VDD = 0V) | Feed 5V to board USB port |
| Wrong colours | Channel order | Confirmed B→G→R |
| Colours washed out | No gamma | Gamma 2.2 |
| Slider "light blue", LED correct | Stale CT attr; HS mode not rendered by Apple | Advertise CT; mirror attrs; boot-normalise HS→XY |
| Sub-second wrong-colour flash | LED applied on ColorMode write before values | Skip mode/RemainingTime writes in callback |
| Brightness snaps to 25% on every toggle | OnLevel = 64 (spec forces it) | OnLevel + StartUpCurrentLevel = null |
| Zones show "off" while LED on | Wi-Fi modem power-save latency | esp_wifi_set_ps(WIFI_PS_NONE) |
| Laggy UI / loading spinner | KBs of CHIP logs per command on Matter thread | Power-save off + CHIP log tags → WARN |
| Can't tap-toggle from tile icon | Composed device, not a bridge | Bridge (Aggregator + bridged nodes) |

### Known / by-design
- Colour transitions step rather than glide — inherent to Matter-over-Wi-Fi
  (~30–50ms RTT) vs Hue's Zigbee; not fixable in firmware.
- Device advertises two operational identities → a stale fabric remains in NVS;
  an `erase-flash` + re-pair cleans it if desired.

---

## Build / flash / monitor

```bash
# Every new terminal:
source ~/esp/esp-idf/export.sh
source ~/esp/esp-matter/export.sh   # only needed for build (sets ESP_MATTER_PATH)

# Main firmware:
cd "firmware" && idf.py -p /dev/cu.usbserial-XXX build flash monitor

# Standalone hardware test:
cd "dm631_test" && idf.py set-target esp32c6 && idf.py -p /dev/cu.usbserial-XXX build flash monitor
```

- Serial port name varies with the USB socket (`/dev/cu.usbserial-210`,
  `-110`, …) — check `ls /dev/cu.*`. If "port busy", an old monitor is still
  open: `lsof /dev/cu.usbserial-XXX` then kill it.
- Apple Home pairing code: **20202021**.
- The repo-root `CMakeLists.txt` is a junk "404" placeholder; the real project
  is in `firmware/`. Always run `idf.py` from `firmware/` (or `dm631_test/`).
- Re-pairing is required after the bridge restructure (Remove Accessory →
  `erase-flash` → re-pair).

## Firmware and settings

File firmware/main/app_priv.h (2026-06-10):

#pragma once
#include <esp_err.h>
#include <esp_matter.h>

// Matter attribute ranges
#define MATTER_BRIGHTNESS    254
#define MATTER_HUE           254
#define MATTER_SATURATION    254

// Standard working ranges used internally
#define STANDARD_BRIGHTNESS  100   // percent  (0–100)
#define STANDARD_HUE         360   // degrees  (0–360)
#define STANDARD_SATURATION  100   // percent  (0–100)

// Power-on defaults
#define DEFAULT_POWER        false
#define DEFAULT_BRIGHTNESS   64    // ~25 % of Matter range
#define DEFAULT_HUE          0
#define DEFAULT_SATURATION   254   // fully saturated

// Number of independently controllable LED zones
// Must match DM631_NUM_ZONES in dm631.h
#define NUM_LIGHT_ZONES      10

typedef void *app_driver_handle_t;

app_driver_handle_t app_driver_light_init(void);
app_driver_handle_t app_driver_button_init(void);

// Register the mapping between a Matter endpoint and a physical zone index (0–9).
// Must be called for each zone before esp_matter::start().
void app_driver_register_endpoint(uint8_t zone, uint16_t endpoint_id);

esp_err_t app_driver_attribute_update(app_driver_handle_t driver_handle,
                                      uint16_t endpoint_id,
                                      uint32_t cluster_id,
                                      uint32_t attribute_id,
                                      esp_matter_attr_val_t *val);

// Reads NVS-persisted attributes for the given endpoint and pushes them to
// the corresponding DM631 zone. Call once per zone after esp_matter::start().
esp_err_t app_driver_light_set_defaults(uint16_t endpoint_id);

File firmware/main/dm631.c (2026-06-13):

#include "dm631.h"
#include "driver/gpio.h"
#include "esp_log.h"
#include <string.h>

static const char *TAG = "dm631";

// Frame layout — matches the original woodenshark firmware
// (Lightpack-master/Firmware/LedDriver.c, hw6 block), empirically confirmed
// on this hardware 2026-06-09:
//   [0x000 pad] [z5.B z5.G z5.R] … [z9.B z9.G z9.R]   ← IC3 (far chip, first data sent)
//   [0x000 pad] [z0.B z0.G z0.R] … [z4.B z4.G z4.R]   ← IC2 (near chip, last data sent)
//   LATCH pulse on GPIO14
//
// Channel order per zone: B first, then G, then R.
// 32 values × 12 bits = 384 bits total, sent MSB-first via GPIO bit-bang.
#define FRAME_VALUES  32

static dm631_color_t s_zones[DM631_NUM_ZONES];
static uint16_t s_vals[FRAME_VALUES];

// Which physical DM631 zone (slot in s_zones, clocked out by build_frame) each
// LED socket is wired to.  Index = LED socket, 0-based (LED 1 = index 0).
// HomeKit "LED N" → this table → the zone that drives box socket N.
//
// Measured on this board 2026-06-12: the near DM631 (IC2, LEDs 1–5) is wired in
// a scrambled order; the far DM631 (IC3, LEDs 6–10) is already sequential.
//   LED 1 → Zone 4     LED 6  → Zone 5
//   LED 2 → Zone 3     LED 7  → Zone 6
//   LED 3 → Zone 0     LED 8  → Zone 7
//   LED 4 → Zone 1     LED 9  → Zone 8
//   LED 5 → Zone 2     LED 10 → Zone 9
static const uint8_t led_to_zone[DM631_NUM_ZONES] = {4, 3, 0, 1, 2, 5, 6, 7, 8, 9};

static void build_frame(void)
{
    int v = 0;

    // IC3 (far) — first 192 bits; they shift all the way through IC2 into IC3.
    s_vals[v++] = 0;
    for (int i = 5; i <= 9; i++) {
        s_vals[v++] = s_zones[i].b;
        s_vals[v++] = s_zones[i].g;
        s_vals[v++] = s_zones[i].r;
    }

    // IC2 (near, MOSI connected directly) — last 192 bits.
    s_vals[v++] = 0;
    for (int i = 0; i <= 4; i++) {
        s_vals[v++] = s_zones[i].b;
        s_vals[v++] = s_zones[i].g;
        s_vals[v++] = s_zones[i].r;
    }
}

esp_err_t dm631_init(void)
{
    memset(s_zones, 0, sizeof(s_zones));

    gpio_config_t cfg = {
        .pin_bit_mask = (1ULL << DM631_GPIO_CLK)
                      | (1ULL << DM631_GPIO_MOSI)
                      | (1ULL << DM631_GPIO_LAT),
        .mode         = GPIO_MODE_OUTPUT,
        .pull_up_en   = GPIO_PULLUP_DISABLE,
        .pull_down_en = GPIO_PULLDOWN_DISABLE,
        .intr_type    = GPIO_INTR_DISABLE,
    };
    ESP_ERROR_CHECK(gpio_config(&cfg));
    gpio_set_level(DM631_GPIO_CLK,  0);
    gpio_set_level(DM631_GPIO_MOSI, 0);
    gpio_set_level(DM631_GPIO_LAT,  0);

    ESP_LOGI(TAG, "init OK (soft SPI) — CLK=GPIO%d MOSI=GPIO%d LAT=GPIO%d",
             DM631_GPIO_CLK, DM631_GPIO_MOSI, DM631_GPIO_LAT);

    // Push an all-zero frame so LEDs start off (clears any power-on garbage).
    dm631_update();

    return ESP_OK;
}

void dm631_set_zone(uint8_t led, dm631_color_t color)
{
    if (led < DM631_NUM_ZONES) {
        s_zones[led_to_zone[led]] = color;   // map LED socket → physical DM631 zone
    }
}

void dm631_set_all(dm631_color_t color)
{
    for (int i = 0; i < DM631_NUM_ZONES; i++) {
        s_zones[i] = color;
    }
}

esp_err_t dm631_update(void)
{
    build_frame();

    // Clock out 32 × 12 bits MSB-first.
    // SPI mode 0: CLK idle LOW, data sampled on rising CLK edge.
    // gpio_set_level() through the ESP32-C6 GPIO matrix adds sufficient
    // setup/hold time (~50 ns) — no explicit delays needed.
    for (int i = 0; i < FRAME_VALUES; i++) {
        uint16_t v = s_vals[i];
        for (int bit = 11; bit >= 0; bit--) {
            gpio_set_level(DM631_GPIO_MOSI, (v >> bit) & 1);
            gpio_set_level(DM631_GPIO_CLK, 1);
            gpio_set_level(DM631_GPIO_CLK, 0);
        }
    }

    // LATCH pulse: rising edge transfers shift register → output latches.
    gpio_set_level(DM631_GPIO_LAT, 1);
    gpio_set_level(DM631_GPIO_LAT, 0);

    return ESP_OK;
}

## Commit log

2026-05-24 Add firmware, schematics and project documentation
    [Lightpack.brd, Lightpack.sch]
2026-05-24 Restore firmware source code
    [partitions.csv]
2026-05-25 Add per-zone HomeKit control and fix RGB colour wheel
    - Refactor firmware for 10 independent Matter endpoints (one per LED zone)
    - app_priv.h: add NUM_LIGHT_ZONES, app_driver_register_endpoint()
    - app_driver.cpp: per-zone state (zone_state_t[10]), apply_zone_to_leds(),
    endpoint_to_zone() mapping, dm631_set_zone() instead of dm631_set_all()
    - app_main.cpp: loop creates 10 extended_color_light endpoints,
    light_endpoint_ids[10] array replaces singular light_endpoint_id
    - Fix RGB colour wheel not showing in Apple Home (FeatureMap fix)
    - Root cause: ODR violation in esp-matter SDK prevents hue_saturation::add()
    from updating ColorControl FeatureMap; Apple Home reads FeatureMa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
    [app_priv.h]
2026-06-10 ESP32-C6: complete hardware bring-up and Matter/HomeKit polish
    Hardware is now fully working end-to-end: all 10 DM631 zones drive correct
    colour and brightness from Apple Home over Matter.
    Driver (dm631.c)
    - Confirm B->G->R channel order against original woodenshark firmware
    - Run at full GPIO speed (remove bit-bang delays; valid with 5V DM631 VDD)
    - Drop boot RGB diagnostic; push an all-zero frame at init instead
    Colour pipeline (app_driver.cpp)
    - Add gamma 2.2 for richer, perceptually-linear colour
    - Mirror every colour change across HS/XY/CT representations so Apple Home
    always reads a consistent value (fixes stale "light blue" slider)
    - Normalise zones to XY colour mode at boot (Appl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
    [LightPack_SDK_Demo.cfg, Lightpack-board.dxf, Lightpack.brd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]
2026-06-13 Map HomeKit zones to physical LED socket numbers
    The firmware zone indices didn't line up with the LED socket numbers
    printed on the Lightpack enclosure: the near DM631 (sockets 1-5) is wired
    in a scrambled order, while the far DM631 (sockets 6-10) is sequential.
    - Add led_to_zone[] remap in dm631.c so logical zone N drives box socket
    N+1 (LED 1 -> physical zone 4, etc.); measured per-socket on the board.
    Applied as a one-line indirection in dm631_set_zone(); build_frame() and
    the Matter layer are untouched.
    - Rename the HomeKit accessory labels "Zone N" -> "LED N" so the tiles read
    in socket terms (takes effect on next pairing).
    No behavior change beyond the corrected zone->socket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
    [dm631.c]
2026-06-13 Simplify colour path to HueSaturation-native
    Apple Home drives colour exclusively with MoveToHueAndSaturation (confirmed
    via on-device command trace), so the device is HS-native. The previous
    machinery that forced XY mode and mirrored every change across HS/XY/CT was
    both unnecessary and the cause of the "all 10 lights at once" update storm:
    each command fanned out into ~8 apply passes plus a flood of attribute
    reports.
    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
2026-06-14 Set device identity (manufacturer / model / serial)
    Each LED tile now reports its own identity via the Bridged Device Basic
    Information cluster, shown in Apple Home's accessory details:
    - VendorName (Hersteller) = "Hesam DIY & Lightpack"
    - ProductName (Modell) = "Lightpack IOT"
    - SerialNumber (Seriennummer) = "20202021"
    The bridge's own serial is set via CONFIG_USE_TEST_SERIAL_NUMBER. The
    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
2026-06-14 Fix HomeKit light-blue swatch: advertise HS+XY only (drop Color Temperature)
    Apple Home mis-renders the colour swatch as a default white/blue on a fresh
    read for lights that advertise Color Temperature alongside Hue/Saturation
    (known Apple-side RGB+CCT bug, also affects Philips Hue). Dropping CT from
    ColorCapabilities and FeatureMap (0x19 -> 0x09, HS+XY) makes Apple treat the
    device as a pure colour light and show the real colour. Confirmed fixed.
    Trade-off: no Temperature tab in the colour picker (RGB device, not needed).
2026-06-14 Override root device VendorName / ProductName via CHIPProjectConfig
    Add firmware/main/CHIPProjectConfig.h (wired through CONFIG_CHIP_PROJECT_CONFIG)
    to set the root-node Basic Information identity that CHIP serves from its
    compiled provider:
    - VendorName = "Hesam DIY & Lightpack"
    - ProductName = "Lightpack IOT"
    This sets the bridge-level Hersteller/Modell shown in Apple Home's accessory
    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
2026-06-14 Map HomeKit zones to physical LED socket numbers
    printed on the Lightpack enclosure: the near DM631 (sockets 1–5) is wired
    in a scrambled order, while the far DM631 (sockets 6–10) is sequential.
    N+1 (LED 1 → physical zone 4, etc.); measured per-socket on the board.
    - Rename the HomeKit accessory labels "Zone N" → "LED N" so the tiles read
    No behavior change beyond the corrected zone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
2026-06-14 Add Wi-Fi UDP ambilight (WLED) with Home/Ambilight mode switching
    Implements screen-sync ambilight alongside the existing Matter/Apple Home
    control, on the same Wi-Fi transport (no re-pair, no transport change).
    - output_controller: single mutex-protected LED output layer with two sources
    (HOME = Matter per-zone colour, AMBILIGHT = UDP full frame). Exactly one
    drives the DM631 at a time; the Matter thread and the UDP task never
    interleave a frame. HOME colours are always kept current so they are
    restored when ambilight stops.
    - ambilight_udp: dedicated task listening on UDP 21324, parsing the WLED
    realtime protocol (DRGB proto 2 and DNRGB proto 4), gamma-correcting
    8-bit sRGB to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
2026-06-14 Add DDP protocol to ambilight receiver for HyperHDR
    HyperHDR's "WLED" device requires the target to also answer a WLED HTTP /json
    handshake (LED-count discovery), which our UDP-only receiver doesn't provide.
    DDP (Distributed Display Protocol) needs no handshake, so it's the clean path
    for a custom device.
    - ambilight_udp now listens on BOTH UDP ports via select():
    21324 WLED realtime (DRGB/DNRGB) — kept for WLED tools + the broadcast test
    4048 DDP — HyperHDR's "DDP" device streams here
    - Shared 8-bit->12-bit gamma + frame-fill helper; malformed packets ignored.
    Verified end-to-end: HyperHDR (macOS, DDP -> ESP IP:4048, 10 LEDs) drives the
    zones from th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
2026-06-14 docs: add ambilight + temp-sensor dev log
2026-06-14 docs: update README and PROJECT_STATUS to current state (Matter + Ambilight)
    Rewrite README accurately: working Matter/HomeKit + Ambilight, corrected power
    wiring (DM631 logic needs board USB 5V), HS+XY colour, DDP/WLED ambilight,
    HyperHDR setup. Add a current-status summary atop PROJECT_STATUS and flag the
    older bring-up sections as historical.
2026-06-14 docs: note languages/toolchain + original-housing stealth retrofit
    - C++ app + C driver, built with ESP-IDF/esp-matter (RISC-V, ESP32-C6).
    - All added electronics fit in the original Lightpack enclosure; the finished
    unit retains the original product's appearance.
2026-06-14 Remove bundled upstream Lightpack sources; link to original instead
    Untrack Lightpack-master/, at90usb162-firmware/ (and keep Lightpack-docs-master/
    ignored) — these are copies of the original Lightpack project (GPL/CC) pulled in
    only for reference. They are now gitignored and referenced from the README's
    Credits section rather than republished here. Drops the repo from ~1207 to ~35
    tracked files. Local copies are kept on disk (not deleted).
    [LightPack_SDK_Demo.cfg, Lightpack-board.dxf, Lightpack.brd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]
2026-06-14 Add MIT LICENSE; remove junk 404 files; untrack original hardware design
    - Add LICENSE (MIT) for the project's own ESP32-C6 firmware + README License note.
    - Delete accidental '404: Not Found' placeholder files (root CMakeLists.txt,
    lightpack-diy-session-log.md).
    - Untrack original Lightpack hardware files (Lightpack.sch/.brd, CC-licensed
    upstream); kept locally, referenced from README Credits.
    [Lightpack.brd, Lightpack.sch]
2026-06-14 docs: add Safety and Disclaimer sections to README
    Independent DIY project; not affiliated/endorsed/certified; uses Matter test
    IDs; build at own risk; power/heat safety notes.
2026-06-15 Remove orphaned root-level build configs (duplicates of firmware/)
    The real partitions.csv / sdkconfig.defaults(.esp32c6) live in firmware/; the
    root copies were leftovers with no project to use them (root CMakeLists.txt was
    the removed 404 junk).
    [partitions.csv]
2026-07-14 Add non-blocking LED fade + fix power-on flicker
    Apple Home sends group on/off as 10 separate, staggered unicast Matter
    commands (confirmed via monitor logs, ~400-900ms apart per zone). Instant
    commits made each LED pop the moment its own command arrived, reading as
    chaotic sequential switching instead of a synchronized group change.
    - output_controller: add a non-blocking ~50Hz fade engine. Home-path writes
    now set a per-zone target; a lightweight esp_timer ramps the displayed
    buffer toward it and commits one atomic DM631 frame per tick (idle ticks
    are no-ops). Overlapping fades across the 10 zones read as one smooth
    group transition, similar to Philips Hue, without needing the net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
